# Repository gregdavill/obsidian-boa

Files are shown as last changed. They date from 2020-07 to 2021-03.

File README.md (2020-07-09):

# Obsidian Boa #

     ~ Current Status: Prototype boards ordered from OSHPark ~
     
     Note: This design was performed in KiCad nightly , you will need a Nightly build to open and edit these source files.

## Bare PCBs:
Order some PCBs
     [OSHPark](https://oshpark.com/shared_projects/r7u7eQDq)

## What is it?
A simple compact ESP32-S2 development board

Form-factor based off [bitsy-v1.0a](https://github.com/icebreaker-fpga/icebreaker/tree/master/hardware/bitsy-v1.0a)

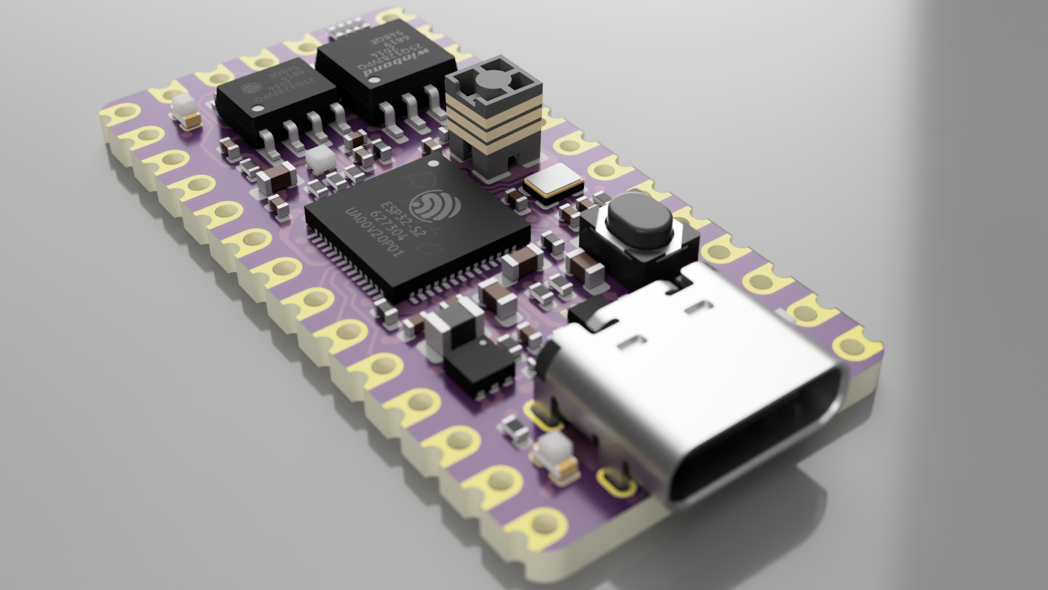
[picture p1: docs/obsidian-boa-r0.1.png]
Render


## What is it?
ESP32-S2 + PSRAM + FLASH

## Licence
 * Hardware in this repository is licenced under Creative Commons BY-SA

 ## OSHW Certification
 TBD (Will apply when prototypes tested)

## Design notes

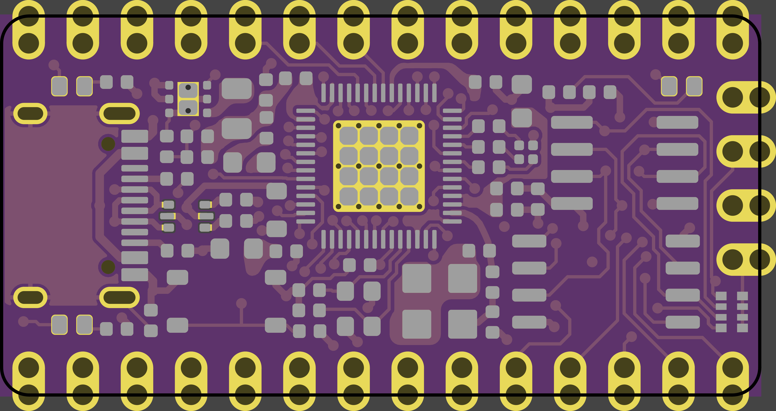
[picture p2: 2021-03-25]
hw/obsidian-boa-r0.1/Production/obsidian-boa-r0.1-Front.png

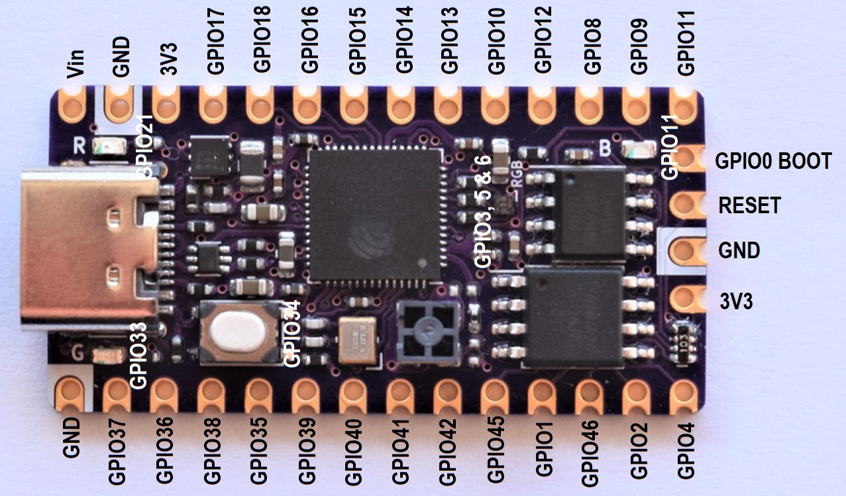
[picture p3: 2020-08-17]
hw/obsidian-boa-r0.1/obsidian-boa-pins-r0.1.jpg

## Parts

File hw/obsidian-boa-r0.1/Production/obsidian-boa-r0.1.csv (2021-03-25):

Source: | /home/greg/Projects/obsidian-boa/hw/obsidian-boa-r0.1/obsidian-boa-r0.1.kicad_sch
Date: | Thu 25 Mar 2021 13:59:01
Tool: | Eeschema 5.99.0-unknown-a9f86c6f3d~118~ubuntu20.10.1
Generator: | /usr/share/kicad-nightly/plugins/bom_csv_grouped_by_value.py
Component Count: | 87
Individual Components:
Item | Qty | Reference(s) | Value | LibPart | Footprint | Datasheet | Mfg | PN | Source
 |  | AE1 | Antenna | Device:Antenna_Shield | obsidian-boa:0479480001 | ~ | Molex | 0479480001
 |  | C1 | 2.2uF | icebreaker-bitsy-rescue:pkl_C_Small-pkl_device | Capacitor_SMD:C_0402_1005Metric |  | Yageo | CC0402MRX5R5BB225
 |  | C2 | 2.2uF | icebreaker-bitsy-rescue:pkl_C_Small-pkl_device | Capacitor_SMD:C_0402_1005Metric |  | Yageo | CC0402MRX5R5BB225
 |  | C3 | 18pF | icebreaker-bitsy-rescue:pkl_C_Small-pkl_device | Capacitor_SMD:C_0402_1005Metric |  | Yageo | CC0402GRNPO9BN180
 |  | C4 | 18pF | icebreaker-bitsy-rescue:pkl_C_Small-pkl_device | Capacitor_SMD:C_0402_1005Metric |  | Yageo | CC0402GRNPO9BN180
 |  | C5 | 10u | Device:C | Capacitor_SMD:C_0603_1608Metric | ~ | Yageo | CC0603KRX5R5BB106
 |  | C6 | 22pF | Device:C | Capacitor_SMD:C_0402_1005Metric | ~ | Yageo | CC0402KRNPO9BN220
 |  | C7 | 2.2uF | Device:C | Capacitor_SMD:C_0402_1005Metric | ~ | Yageo | CC0402MRX5R5BB225
 |  | C8 | 10u | icebreaker-bitsy-rescue:pkl_C-pkl_device | Capacitor_SMD:C_0603_1608Metric |  | Yageo | CC0603KRX5R5BB106
 |  | C9 | 100n | icebreaker-bitsy-rescue:pkl_C_Small-pkl_device | Capacitor_SMD:C_0402_1005Metric |  | Yageo | CC0402ZRY5V7BB104
 |  | C10 | TBD | icebreaker-bitsy-rescue:pkl_C_Small-pkl_device | Capacitor_SMD:C_0402_1005Metric |  |  | DNP | ANY
 |  | C11 | TBD | icebreaker-bitsy-rescue:pkl_C_Small-pkl_device | Capacitor_SMD:C_0402_1005Metric |  |  | DNP | ANY
 |  | C12 | 100n | icebreaker-bitsy-rescue:pkl_C_Small-pkl_device | Capacitor_SMD:C_0402_1005Metric |  | Yageo | CC0402ZRY5V7BB104
 |  | C13 | 100n | icebreaker-bitsy-rescue:pkl_C_Small-pkl_device | Capacitor_SMD:C_0402_1005Metric |  | Yageo | CC0402ZRY5V7BB104
 |  | C14 | 10u | icebreaker-bitsy-rescue:pkl_C-pkl_device | Capacitor_SMD:C_0603_1608Metric |  | Yageo | CC0603KRX5R5BB106
 |  | C15 | 100n | icebreaker-bitsy-rescue:pkl_C_Small-pkl_device | Capacitor_SMD:C_0402_1005Metric |  | Yageo | CC0402ZRY5V7BB104
 |  | C19 | 10u | icebreaker-bitsy-rescue:pkl_C-pkl_device | Capacitor_SMD:C_0603_1608Metric |  | Yageo | CC0603KRX5R5BB106
 |  | D1 | RED | Device:LED_ALT | obsidian-boa:LED_0603_1608Metric_Compact | ~ | Lite-On Inc. | LTST-C191KRKT
 |  | D2 | GRN | Device:LED_ALT | obsidian-boa:LED_0603_1608Metric_Compact | ~ | Lite-On Inc. | LTST-C191KGKT
 |  | D3 | BLU | Device:LED_ALT | obsidian-boa:LED_0603_1608Metric_Compact | ~ | Lite-On Inc. | LTST-C191TBKT
 |  | D4 | MHPA1010RGBDT | Device:LED_ARBG | LED_SMD:LED_Lumex_SML-LX0303SIUPGUSB | ~ | MEIHUA | MHPA1010RGBDT
 |  | FB1 | 240R | Device:Ferrite_Bead_Small | Inductor_SMD:L_0402_1005Metric | ~ | Murata Electronics | BLM15BC241SN1D
 |  | FB2 | 240R | Device:Ferrite_Bead_Small | Inductor_SMD:L_0402_1005Metric | ~ | Murata Electronics | BLM15BC241SN1D
 |  | FB3 | 240R | Device:Ferrite_Bead_Small | Inductor_SMD:L_0402_1005Metric | ~ | Murata Electronics | BLM15BC241SN1D
 |  | J1 | USB_C | Connector:USB_C_Receptacle_USB2.0 | pkl_connectors:USB_C_Receptacle_HRO_TYPE-C-31-M-12 | https://www.usb.org/sites/default/files/documents/usb_type-c.zip | GCT | USB4105-GF-A
 |  | J2 | PROG | Connector_Generic:Conn_02x05_Odd_Even | pkl_pin_headers:PinHeader_2x05_P2.54mm_Vertical_SMD | ~
 |  | JP1 | Jumper | icebreaker-bitsy-rescue:pkl_jumper_nc-pkl_misc | Jumper:SolderJumper-2_P1.3mm_Bridged2Bar_RoundedPad1.0x1.5mm |  |  |  | ANY
 |  | L1 | 2.2uH | Device:L_Small | Inductor_SMD:L_0805_2012Metric | ~ | TAI-TECH | CPI201210UF-2R2M-0A8
 |  | L2 | TBD | Device:L_Small | Inductor_SMD:L_0402_1005Metric | ~ | Yageo | RC0402FR-070RL
 |  | P0 | 0 | Connector_Generic:Conn_01x01 | pkl_pin_headers:Pin_Header_Straight_Round_1x01_Castellated | ~ |  |  | ANY
 |  | P1 | 1 | Connector_Generic:Conn_01x01 | pkl_pin_headers:Pin_Header_Straight_Round_1x01_Castellated | ~ |  |  | ANY
 |  | P2 | 2 | Connector_Generic:Conn_01x01 | pkl_pin_headers:Pin_Header_Straight_Round_1x01_Castellated | ~ |  |  | ANY
 |  | P3 | 3 | Connector_Generic:Conn_01x01 | pkl_pin_headers:Pin_Header_Straight_Round_1x01_Castellated | ~ |  |  | ANY
 |  | P4 | 4 | Connector_Generic:Conn_01x01 | pkl_pin_headers:Pin_Header_Straight_Round_1x01_Castellated | ~ |  |  | ANY
 |  | P5 | 5 | Connector_Generic:Conn_01x01 | pkl_pin_headers:Pin_Header_Straight_Round_1x01_Castellated | ~ |  |  | ANY
 |  | P6 | 6 | Connector_Generic:Conn_01x01 | pkl_pin_headers:Pin_Header_Straight_Round_1x01_Castellated | ~ |  |  | ANY
 |  | P7 | 7 | Connector_Generic:Conn_01x01 | pkl_pin_headers:Pin_Header_Straight_Round_1x01_Castellated | ~ |  |  | ANY
 |  | P8 | 8 | Connector_Generic:Conn_01x01 | pkl_pin_headers:Pin_Header_Straight_Round_1x01_Castellated | ~ |  |  | ANY
 |  | P9 | 9 | Connector_Generic:Conn_01x01 | pkl_pin_headers:Pin_Header_Straight_Round_1x01_Castellated | ~ |  |  | ANY
 |  | P10 | 10 | Connector_Generic:Conn_01x01 | pkl_pin_headers:Pin_Header_Straight_Round_1x01_Castellated | ~ |  |  | ANY
 |  | P11 | 11 | Connector_Generic:Conn_01x01 | pkl_pin_headers:Pin_Header_Straight_Round_1x01_Castellated | ~ |  |  | ANY
 |  | P12 | 12 | Connector_Generic:Conn_01x01 | pkl_pin_headers:Pin_Header_Straight_Round_1x01_Castellated | ~ |  |  | ANY
 |  | P13 | 13 | Connector_Generic:Conn_01x01 | pkl_pin_headers:Pin_Header_Straight_Round_1x01_Castellated | ~ |  |  | ANY
 |  | P14 | 14 | Connector_Generic:Conn_01x01 | pkl_pin_headers:Pin_Header_Straight_Round_1x01_Castellated | ~ |  |  | ANY
 |  | P15 | 15 | Connector_Generic:Conn_01x01 | pkl_pin_headers:Pin_Header_Straight_Round_1x01_Castellated | ~ |  |  | ANY
 |  | P16 | 16 | Connector_Generic:Conn_01x01 | pkl_pin_headers:Pin_Header_Straight_Round_1x01_Castellated | ~ |  |  | ANY
 |  | P17 | 17 | Connector_Generic:Conn_01x01 | pkl_pin_headers:Pin_Header_Straight_Round_1x01_Castellated | ~ |  |  | ANY
 |  | P18 | 18 | Connector_Generic:Conn_01x01 | pkl_pin_headers:Pin_Header_Straight_Round_1x01_Castellated | ~ |  |  | ANY
 |  | P19 | 19 | Connector_Generic:Conn_01x01 | pkl_pin_headers:Pin_Header_Straight_Round_1x01_Castellated | ~ |  |  | ANY
 |  | P20 | 20 | Connector_Generic:Conn_01x01 | pkl_pin_headers:Pin_Header_Straight_Round_1x01_Castellated | ~ |  |  | ANY
 |  | P21 | 21 | Connector_Generic:Conn_01x01 | pkl_pin_headers:Pin_Header_Straight_Round_1x01_Castellated | ~ |  |  | ANY
 |  | P22 | 22 | Connector_Generic:Conn_01x01 | pkl_pin_headers:Pin_Header_Straight_Round_1x01_Castellated | ~ |  |  | ANY
 |  | P23 | 23 | Connector_Generic:Conn_01x01 | pkl_pin_headers:Pin_Header_Straight_Round_1x01_Castellated | ~ |  |  | ANY
 |  | P24 | GND | Connector_Generic:Conn_01x01 | pkl_pin_headers:Pin_Header_Straight_Round_1x01_Castellated | ~ |  |  | ANY
 |  | P25 | GND | Connector_Generic:Conn_01x01 | pkl_pin_headers:Pin_Header_Straight_Round_1x01_Castellated | ~ |  |  | ANY
 |  | P26 | GND | Connector_Generic:Conn_01x01 | pkl_pin_headers:Pin_Header_Straight_Round_1x01_Castellated | ~ |  |  | ANY
 |  | P27 | 3V3 | Connector_Generic:Conn_01x01 | pkl_pin_headers:Pin_Header_Straight_Round_1x01_Castellated | ~ |  |  | ANY
 |  | P28 | 3V3 | Connector_Generic:Conn_01x01 | pkl_pin_headers:Pin_Header_Straight_Round_1x01_Castellated | ~ |  |  | ANY
 |  | P29 | VIN | Connector_Generic:Conn_01x01 | pkl_pin_headers:Pin_Header_Straight_Round_1x01_Castellated | ~ |  |  | ANY
 |  | P30 | CDONE | Connector_Generic:Conn_01x01 | pkl_pin_headers:Pin_Header_Straight_Round_1x01_Castellated | ~ |  |  | ANY
 |  | P31 | CRESET | Connector_Generic:Conn_01x01 | pkl_pin_headers:Pin_Header_Straight_Round_1x01_Castellated | ~ |  |  | ANY
 |  | P32 | UP | icebreaker-bitsy-rescue:PAD_SMD-pkl_misc | pkl_pads:PAD_SMD_1x2.65_ROUNDED |  |  |  | ANY
 |  | P33 | UP | icebreaker-bitsy-rescue:PAD_SMD-pkl_misc | pkl_pads:PAD_SMD_1x2.65_ROUNDED |  |  |  | ANY
 |  | P34 | UP | icebreaker-bitsy-rescue:PAD_SMD-pkl_misc | pkl_pads:PAD_SMD_1x2.65_ROUNDED |  |  |  | ANY
 |  | P35 | UP | icebreaker-bitsy-rescue:PAD_SMD-pkl_misc | pkl_pads:PAD_SMD_1x2.65_ROUNDED |  |  |  | ANY
 |  | R1 | 1M | icebreaker-bitsy-rescue:pkl_R_Small-pkl_device | Resistor_SMD:R_0402_1005Metric |  | Yageo | RC0402FR-071ML
 |  | R2 | 5k1 | icebreaker-bitsy-rescue:pkl_R_Small-pkl_device | Resistor_SMD:R_0402_1005Metric |  | Yageo | RC0402FR-075K1L
 |  | R3 | 5k1 | icebreaker-bitsy-rescue:pkl_R_Small-pkl_device | Resistor_SMD:R_0402_1005Metric |  | Yageo | RC0402FR-075K1L
 |  | R4 | 22E | icebreaker-bitsy-rescue:pkl_R_Small-pkl_device | Resistor_SMD:R_0402_1005Metric |  | Yageo | RC0402FR-0722RL
 |  | R5 | 22E | icebreaker-bitsy-rescue:pkl_R_Small-pkl_device | Resistor_SMD:R_0402_1005Metric |  | Yageo | RC0402FR-0722RL
 |  | R6 | 2k2 | icebreaker-bitsy-rescue:pkl_R_Small-pkl_device | Resistor_SMD:R_0402_1005Metric |  | Yageo | RC0402FR-072K2L
 |  | R7 | 453k | Device:R | Resistor_SMD:R_0402_1005Metric | ~ | Yageo | RC0402FR-07453KL
 |  | R8 | 100k | Device:R | Resistor_SMD:R_0402_1005Metric | ~ | Yageo | RC0402FR-07100KL
 |  | R9 | 2k2 | icebreaker-bitsy-rescue:pkl_R_Small-pkl_device | Resistor_SMD:R_0402_1005Metric |  | Yageo | RC0402FR-072K2L
 |  | R10 | 10k | icebreaker-bitsy-rescue:pkl_R_Small-pkl_device | Resistor_SMD:R_0402_1005Metric |  | Yageo | RC0402FR-0710KL
 |  | R11 | 330E | icebreaker-bitsy-rescue:pkl_R_Small-pkl_device | Resistor_SMD:R_0402_1005Metric |  | Yageo | RC0402FR-07330RL
 |  | R12 | 330E | icebreaker-bitsy-rescue:pkl_R_Small-pkl_device | Resistor_SMD:R_0402_1005Metric |  | Yageo | RC0402FR-07330RL
 |  | R13 | 2k2 | icebreaker-bitsy-rescue:pkl_R_Small-pkl_device | Resistor_SMD:R_0402_1005Metric |  | Yageo | RC0402FR-072K2L
 |  | R14 | 2k2 | icebreaker-bitsy-rescue:pkl_R_Small-pkl_device | Resistor_SMD:R_0402_1005Metric |  | Yageo | RC0402FR-072K2L
 |  | RN1 | 10k | Device:R_Pack04_Split | Resistor_SMD:R_Array_Convex_4x0402 | ~ | Yageo | YC124-FR-0710KL
 |  | SW1 | TACT | icebreaker-bitsy-rescue:TACT-pkl_misc | pkl_buttons_switches:SW_SPST_3x4x2.5 |  | C&K | PTS810
 |  | U1 | USBLC6-2 | icebreaker-bitsy-rescue:USBLC6-2-pkl_misc | pkl_housings_sot:SOT-666 |  | STMicroelectronics | USBLC6-2P6
 |  | U2 | LY68L6400SLIT | Memory_Flash:W25Q32JVSS | Package_SO:SOIC-8_3.9x4.9mm_P1.27mm | http://www.winbond.com/resource-files/w25q32jv%20revg%2003272018%20plus.pdf | Lyontek Inc. | LY68L6400SLIT
 |  | U3 | ESP32-S2 | obsidian-boa:ESP32-S2 | Package_DFN_QFN:QFN-56-1EP_7x7mm_P0.4mm_EP5.6x5.6mm |  | Espressif Systems | ESP32-S2
 |  | U4 | W25Q128JV | Memory_Flash:W25Q32JVSS | Package_SO:SOIC-8_5.23x5.23mm_P1.27mm | http://www.winbond.com/resource-files/w25q32jv%20revg%2003272018%20plus.pdf | Winbond Electronics | W25Q128JVSIQ TR
 |  | U5 | TPS62290 | gkl_pmic:TPS62290 | Package_SON:WSON-6-1EP_2x2mm_P0.65mm_EP1x1.6mm_ThermalVias |  | Texas Instruments | TPS62290DRVR
 |  | Y1 | 40MHz | Device:Crystal_GND24_Small | Crystal:Crystal_SMD_Abracon_ABM10-4Pin_2.5x2.0mm | ~ | ECS Inc. | ECS-400-10-36B-CKY-TR
Collated Components:
Item | Qty | Reference(s) | Value | LibPart | Footprint | Datasheet | Mfg | PN | Source
1 | 1 | AE1 | Antenna | Device:Antenna_Shield | obsidian-boa:0479480001 | ~ | Molex | 0479480001
2 | 2 | C1, C2 | 2.2uF | icebreaker-bitsy-rescue:pkl_C_Small-pkl_device | Capacitor_SMD:C_0402_1005Metric |  | Yageo | CC0402MRX5R5BB225
3 | 2 | C3, C4 | 18pF | icebreaker-bitsy-rescue:pkl_C_Small-pkl_device | Capacitor_SMD:C_0402_1005Metric |  | Yageo | CC0402GRNPO9BN180
4 | 1 | C5 | 10u | Device:C | Capacitor_SMD:C_0603_1608Metric | ~ | Yageo | CC0603KRX5R5BB106
5 | 1 | C6 | 22pF | Device:C | Capacitor_SMD:C_0402_1005Metric | ~ | Yageo | CC0402KRNPO9BN220
6 | 1 | C7 | 2.2uF | Device:C | Capacitor_SMD:C_0402_1005Metric | ~ | Yageo | CC0402MRX5R5BB225
7 | 3 | C8, C14, C19 | 10u | icebreaker-bitsy-rescue:pkl_C-pkl_device | Capacitor_SMD:C_0603_1608Metric |  | Yageo | CC0603KRX5R5BB106
8 | 4 | C9, C12, C13, C15 | 100n | icebreaker-bitsy-rescue:pkl_C_Small-pkl_device | Capacitor_SMD:C_0402_1005Metric |  | Yageo | CC0402ZRY5V7BB104
9 | 2 | C10, C11 | TBD | icebreaker-bitsy-rescue:pkl_C_Small-pkl_device | Capacitor_SMD:C_0402_1005Metric |  |  | DNP | ANY
10 | 1 | D1 | RED | Device:LED_ALT | obsidian-boa:LED_0603_1608Metric_Compact | ~ | Lite-On Inc. | LTST-C191KRKT
11 | 1 | D2 | GRN | Device:LED_ALT | obsidian-boa:LED_0603_1608Metric_Compact | ~ | Lite-On Inc. | LTST-C191KGKT
12 | 1 | D3 | BLU | Device:LED_ALT | obsidian-boa:LED_0603_1608Metric_Compact | ~ | Lite-On Inc. | LTST-C191TBKT
13 | 1 | D4 | MHPA1010RGBDT | Device:LED_ARBG | LED_SMD:LED_Lumex_SML-LX0303SIUPGUSB | ~ | MEIHUA | MHPA1010RGBDT
14 | 3 | FB1, FB2, FB3 | 240R | Device:Ferrite_Bead_Small | Inductor_SMD:L_0402_1005Metric | ~ | Murata Electronics | BLM15BC241SN1D
15 | 1 | J1 | USB_C | Connector:USB_C_Receptacle_USB2.0 | pkl_connectors:USB_C_Receptacle_HRO_TYPE-C-31-M-12 | https://www.usb.org/sites/default/files/documents/usb_type-c.zip | GCT | USB4105-GF-A
16 | 1 | J2 | PROG | Connector_Generic:Conn_02x05_Odd_Even | pkl_pin_headers:PinHeader_2x05_P2.54mm_Vertical_SMD | ~
17 | 1 | JP1 | Jumper | icebreaker-bitsy-rescue:pkl_jumper_nc-pkl_misc | Jumper:SolderJumper-2_P1.3mm_Bridged2Bar_RoundedPad1.0x1.5mm |  |  |  | ANY
18 | 1 | L1 | 2.2uH | Device:L_Small | Inductor_SMD:L_0805_2012Metric | ~ | TAI-TECH | CPI201210UF-2R2M-0A8
19 | 1 | L2 | TBD | Device:L_Small | Inductor_SMD:L_0402_1005Metric | ~ | Yageo | RC0402FR-070RL
20 | 1 | P0 | 0 | Connector_Generic:Conn_01x01 | pkl_pin_headers:Pin_Header_Straight_Round_1x01_Castellated | ~ |  |  | ANY
21 | 1 | P1 | 1 | Connector_Generic:Conn_01x01 | pkl_pin_headers:Pin_Header_Straight_Round_1x01_Castellated | ~ |  |  | ANY
22 | 1 | P2 | 2 | Connector_Generic:Conn_01x01 | pkl_pin_headers:Pin_Header_Straight_Round_1x01_Castellated | ~ |  |  | ANY
23 | 1 | P3 | 3 | Connector_Generic:Conn_01x01 | pkl_pin_headers:Pin_Header_Straight_Round_1x01_Castellated | ~ |  |  | ANY
24 | 1 | P4 | 4 | Connector_Generic:Conn_01x01 | pkl_pin_headers:Pin_Header_Straight_Round_1x01_Castellated | ~ |  |  | ANY
25 | 1 | P5 | 5 | Connector_Generic:Conn_01x01 | pkl_pin_headers:Pin_Header_Straight_Round_1x01_Castellated | ~ |  |  | ANY
26 | 1 | P6 | 6 | Connector_Generic:Conn_01x01 | pkl_pin_headers:Pin_Header_Straight_Round_1x01_Castellated | ~ |  |  | ANY
27 | 1 | P7 | 7 | Connector_Generic:Conn_01x01 | pkl_pin_headers:Pin_Header_Straight_Round_1x01_Castellated | ~ |  |  | ANY
28 | 1 | P8 | 8 | Connector_Generic:Conn_01x01 | pkl_pin_headers:Pin_Header_Straight_Round_1x01_Castellated | ~ |  |  | ANY
29 | 1 | P9 | 9 | Connector_Generic:Conn_01x01 | pkl_pin_headers:Pin_Header_Straight_Round_1x01_Castellated | ~ |  |  | ANY
30 | 1 | P10 | 10 | Connector_Generic:Conn_01x01 | pkl_pin_headers:Pin_Header_Straight_Round_1x01_Castellated | ~ |  |  | ANY
31 | 1 | P11 | 11 | Connector_Generic:Conn_01x01 | pkl_pin_headers:Pin_Header_Straight_Round_1x01_Castellated | ~ |  |  | ANY
32 | 1 | P12 | 12 | Connector_Generic:Conn_01x01 | pkl_pin_headers:Pin_Header_Straight_Round_1x01_Castellated | ~ |  |  | ANY
33 | 1 | P13 | 13 | Connector_Generic:Conn_01x01 | pkl_pin_headers:Pin_Header_Straight_Round_1x01_Castellated | ~ |  |  | ANY
34 | 1 | P14 | 14 | Connector_Generic:Conn_01x01 | pkl_pin_headers:Pin_Header_Straight_Round_1x01_Castellated | ~ |  |  | ANY
35 | 1 | P15 | 15 | Connector_Generic:Conn_01x01 | pkl_pin_headers:Pin_Header_Straight_Round_1x01_Castellated | ~ |  |  | ANY
36 | 1 | P16 | 16 | Connector_Generic:Conn_01x01 | pkl_pin_headers:Pin_Header_Straight_Round_1x01_Castellated | ~ |  |  | ANY
37 | 1 | P17 | 17 | Connector_Generic:Conn_01x01 | pkl_pin_headers:Pin_Header_Straight_Round_1x01_Castellated | ~ |  |  | ANY
38 | 1 | P18 | 18 | Connector_Generic:Conn_01x01 | pkl_pin_headers:Pin_Header_Straight_Round_1x01_Castellated | ~ |  |  | ANY
39 | 1 | P19 | 19 | Connector_Generic:Conn_01x01 | pkl_pin_headers:Pin_Header_Straight_Round_1x01_Castellated | ~ |  |  | ANY
40 | 1 | P20 | 20 | Connector_Generic:Conn_01x01 | pkl_pin_headers:Pin_Header_Straight_Round_1x01_Castellated | ~ |  |  | ANY
41 | 1 | P21 | 21 | Connector_Generic:Conn_01x01 | pkl_pin_headers:Pin_Header_Straight_Round_1x01_Castellated | ~ |  |  | ANY
42 | 1 | P22 | 22 | Connector_Generic:Conn_01x01 | pkl_pin_headers:Pin_Header_Straight_Round_1x01_Castellated | ~ |  |  | ANY
43 | 1 | P23 | 23 | Connector_Generic:Conn_01x01 | pkl_pin_headers:Pin_Header_Straight_Round_1x01_Castellated | ~ |  |  | ANY
44 | 3 | P24, P25, P26 | GND | Connector_Generic:Conn_01x01 | pkl_pin_headers:Pin_Header_Straight_Round_1x01_Castellated | ~ |  |  | ANY
45 | 2 | P27, P28 | 3V3 | Connector_Generic:Conn_01x01 | pkl_pin_headers:Pin_Header_Straight_Round_1x01_Castellated | ~ |  |  | ANY
46 | 1 | P29 | VIN | Connector_Generic:Conn_01x01 | pkl_pin_headers:Pin_Header_Straight_Round_1x01_Castellated | ~ |  |  | ANY
47 | 1 | P30 | CDONE | Connector_Generic:Conn_01x01 | pkl_pin_headers:Pin_Header_Straight_Round_1x01_Castellated | ~ |  |  | ANY
48 | 1 | P31 | CRESET | Connector_Generic:Conn_01x01 | pkl_pin_headers:Pin_Header_Straight_Round_1x01_Castellated | ~ |  |  | ANY
49 | 4 | P32, P33, P34, P35 | UP | icebreaker-bitsy-rescue:PAD_SMD-pkl_misc | pkl_pads:PAD_SMD_1x2.65_ROUNDED |  |  |  | ANY
50 | 1 | R1 | 1M | icebreaker-bitsy-rescue:pkl_R_Small-pkl_device | Resistor_SMD:R_0402_1005Metric |  | Yageo | RC0402FR-071ML
51 | 2 | R2, R3 | 5k1 | icebreaker-bitsy-rescue:pkl_R_Small-pkl_device | Resistor_SMD:R_0402_1005Metric |  | Yageo | RC0402FR-075K1L
52 | 2 | R4, R5 | 22E | icebreaker-bitsy-rescue:pkl_R_Small-pkl_device | Resistor_SMD:R_0402_1005Metric |  | Yageo | RC0402FR-0722RL
53 | 4 | R6, R9, R13, R14 | 2k2 | icebreaker-bitsy-rescue:pkl_R_Small-pkl_device | Resistor_SMD:R_0402_1005Metric |  | Yageo | RC0402FR-072K2L
54 | 1 | R7 | 453k | Device:R | Resistor_SMD:R_0402_1005Metric | ~ | Yageo | RC0402FR-07453KL
55 | 1 | R8 | 100k | Device:R | Resistor_SMD:R_0402_1005Metric | ~ | Yageo | RC0402FR-07100KL
56 | 1 | R10 | 10k | icebreaker-bitsy-rescue:pkl_R_Small-pkl_device | Resistor_SMD:R_0402_1005Metric |  | Yageo | RC0402FR-0710KL
57 | 2 | R11, R12 | 330E | icebreaker-bitsy-rescue:pkl_R_Small-pkl_device | Resistor_SMD:R_0402_1005Metric |  | Yageo | RC0402FR-07330RL
58 | 1 | RN1 | 10k | Device:R_Pack04_Split | Resistor_SMD:R_Array_Convex_4x0402 | ~ | Yageo | YC124-FR-0710KL
59 | 1 | SW1 | TACT | icebreaker-bitsy-rescue:TACT-pkl_misc | pkl_buttons_switches:SW_SPST_3x4x2.5 |  | C&K | PTS810
60 | 1 | U1 | USBLC6-2 | icebreaker-bitsy-rescue:USBLC6-2-pkl_misc | pkl_housings_sot:SOT-666 |  | STMicroelectronics | USBLC6-2P6
61 | 1 | U2 | LY68L6400SLIT | Memory_Flash:W25Q32JVSS | Package_SO:SOIC-8_3.9x4.9mm_P1.27mm | http://www.winbond.com/resource-files/w25q32jv%20revg%2003272018%20plus.pdf | Lyontek Inc. | LY68L6400SLIT
62 | 1 | U3 | ESP32-S2 | obsidian-boa:ESP32-S2 | Package_DFN_QFN:QFN-56-1EP_7x7mm_P0.4mm_EP5.6x5.6mm |  | Espressif Systems | ESP32-S2
63 | 1 | U4 | W25Q128JV | Memory_Flash:W25Q32JVSS | Package_SO:SOIC-8_5.23x5.23mm_P1.27mm | http://www.winbond.com/resource-files/w25q32jv%20revg%2003272018%20plus.pdf | Winbond Electronics | W25Q128JVSIQ TR
64 | 1 | U5 | TPS62290 | gkl_pmic:TPS62290 | Package_SON:WSON-6-1EP_2x2mm_P0.65mm_EP1x1.6mm_ThermalVias |  | Texas Instruments | TPS62290DRVR
65 | 1 | Y1 | 40MHz | Device:Crystal_GND24_Small | Crystal:Crystal_SMD_Abracon_ABM10-4Pin_2.5x2.0mm | ~ | ECS Inc. | ECS-400-10-36B-CKY-TR

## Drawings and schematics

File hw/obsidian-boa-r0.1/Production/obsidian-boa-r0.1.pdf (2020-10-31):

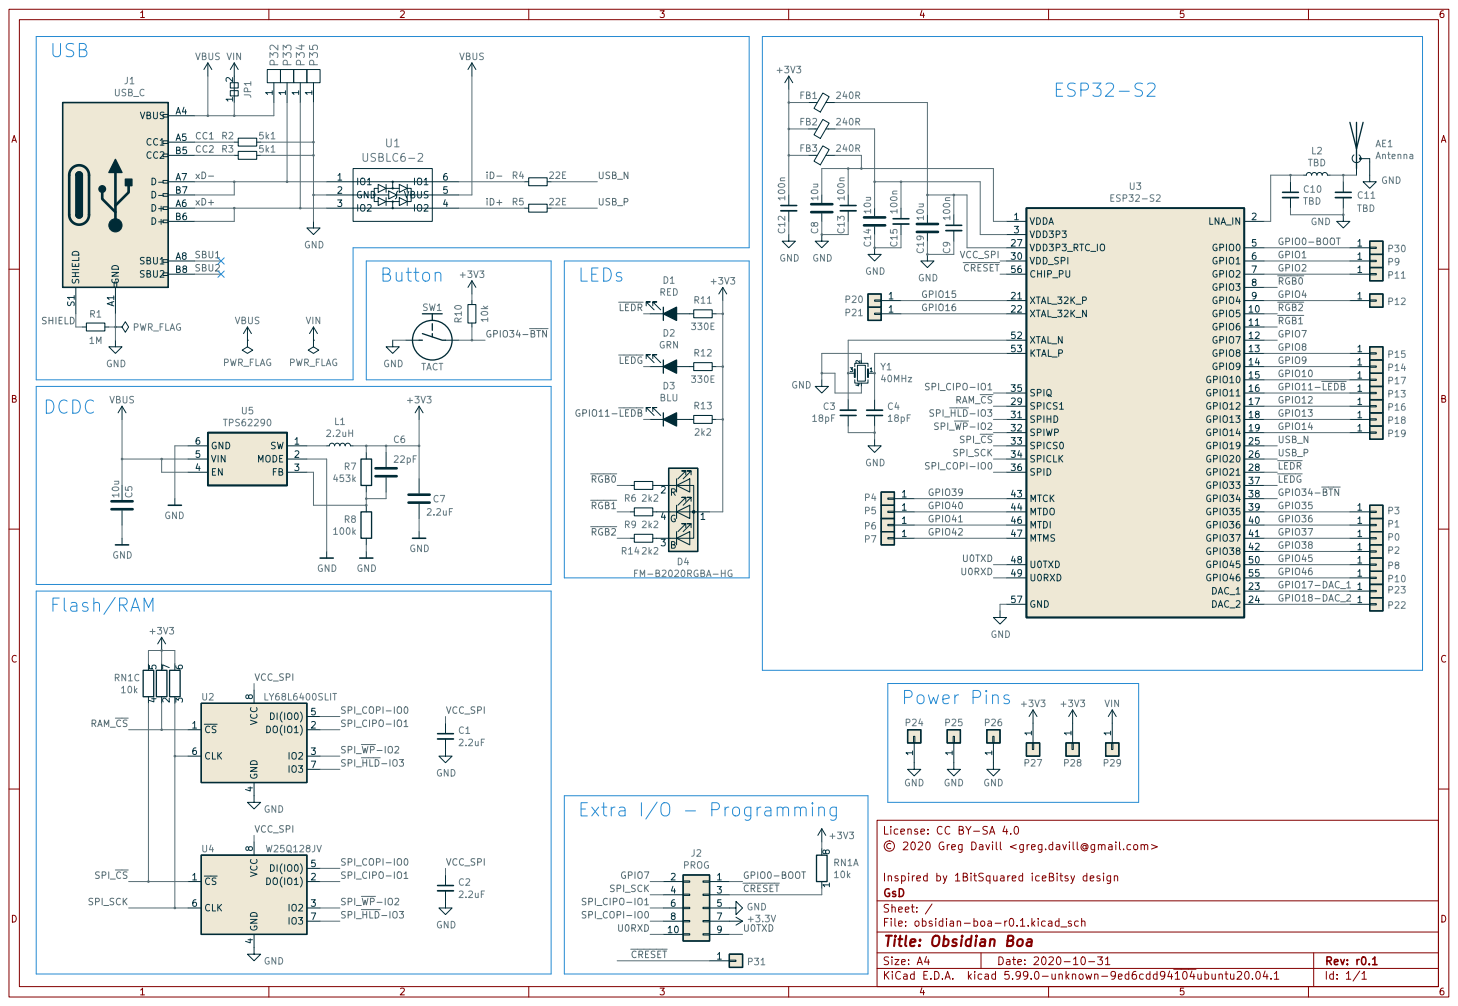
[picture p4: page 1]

License: CC BY-SA 4.0GND

Inspired by 1BitSquared iceBitsy design
File: obsidian-boa-r0.1.kicad_sch Sheet: / GsD

Id: 1/1 Title: Obsidian Boa

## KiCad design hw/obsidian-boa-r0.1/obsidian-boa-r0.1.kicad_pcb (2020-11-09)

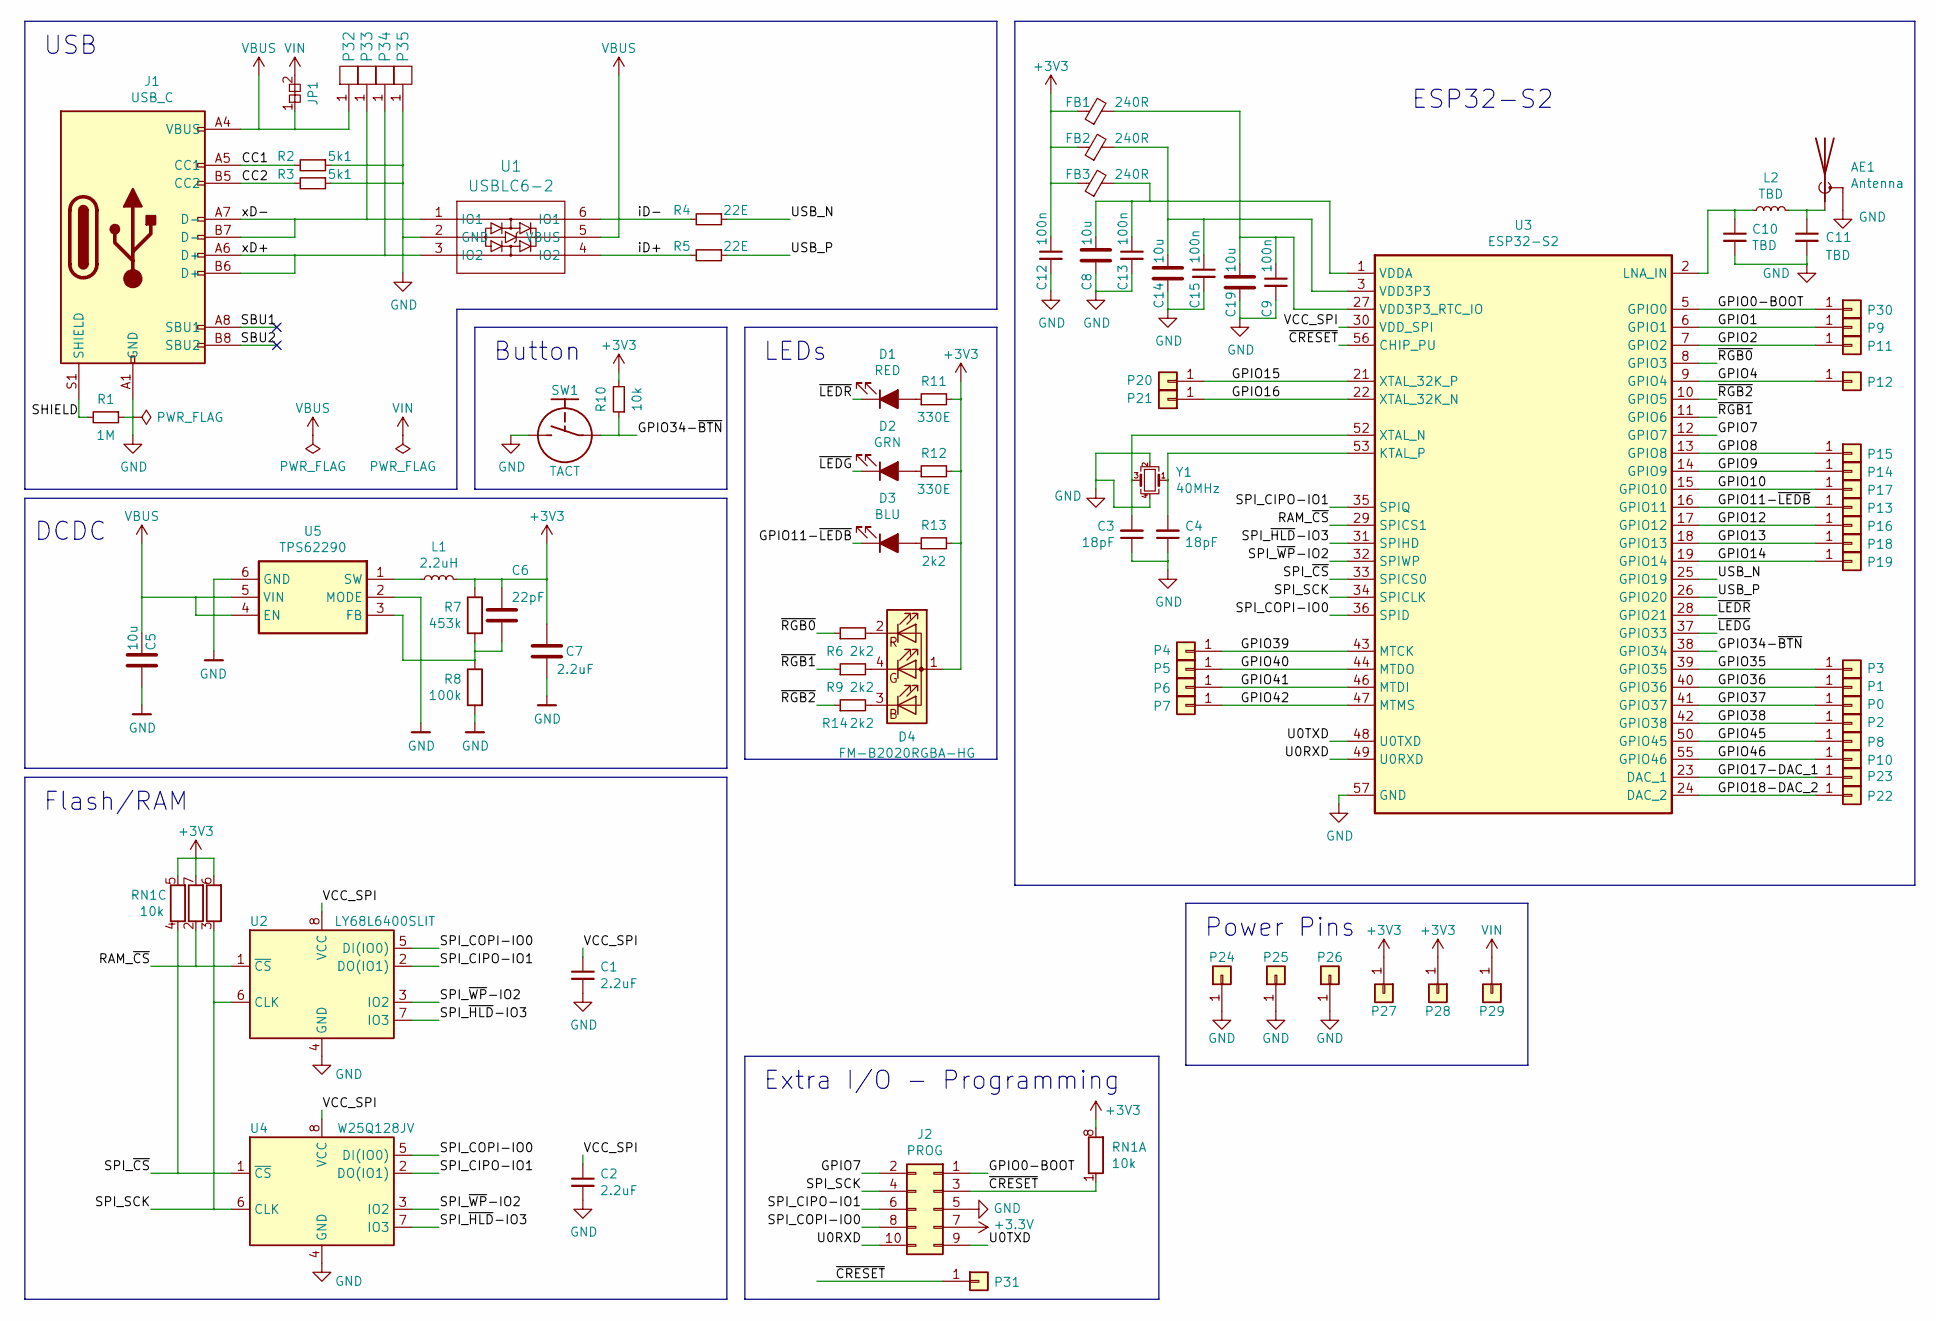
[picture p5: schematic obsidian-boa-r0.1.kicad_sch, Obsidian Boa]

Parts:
AE1: Antenna; 0479480001
C1, C2, C7: 2.2uF; C_0402_1005Metric
C3, C4: 18pF; C_0402_1005Metric
C5, C8, C14, C19: 10u; C_0603_1608Metric
C6: 22pF; C_0402_1005Metric
C9, C12, C13, C15: 100n; C_0402_1005Metric
C10, C11: TBD; C_0402_1005Metric
D1: RED; LED_0603_1608Metric_Compact
D2: GRN; LED_0603_1608Metric_Compact
D3: BLU; LED_0603_1608Metric_Compact
D4: FM-B2020RGBA-HG; LED_Lumex_SML-LX0303SIUPGUSB
FB1, FB2, FB3: 240R; L_0402_1005Metric
J1: USB_C; USB_C_Receptacle_HRO_TYPE-C-31-M-12
J2: PROG; PinHeader_2x05_P2.54mm_Vertical_SMD
JP1: Jumper; SolderJumper-2_P1.3mm_Bridged2Bar_RoundedPad1.0x1.5mm
L1: 2.2uH; L_0805_2012Metric
L2: TBD; L_0402_1005Metric
P0: 0; Pin_Header_Straight_Round_1x01_Castellated
P1: 1; Pin_Header_Straight_Round_1x01_Castellated
P2: 2; Pin_Header_Straight_Round_1x01_Castellated
P3: 3; Pin_Header_Straight_Round_1x01_Castellated
P4: 4; Pin_Header_Straight_Round_1x01_Castellated
P5: 5; Pin_Header_Straight_Round_1x01_Castellated
P6: 6; Pin_Header_Straight_Round_1x01_Castellated
P7: 7; Pin_Header_Straight_Round_1x01_Castellated
P8: 8; Pin_Header_Straight_Round_1x01_Castellated
P9: 9; Pin_Header_Straight_Round_1x01_Castellated
P10: 10; Pin_Header_Straight_Round_1x01_Castellated
P11: 11; Pin_Header_Straight_Round_1x01_Castellated
P12: 12; Pin_Header_Straight_Round_1x01_Castellated
P13: 13; Pin_Header_Straight_Round_1x01_Castellated
P14: 14; Pin_Header_Straight_Round_1x01_Castellated
P15: 15; Pin_Header_Straight_Round_1x01_Castellated
P16: 16; Pin_Header_Straight_Round_1x01_Castellated
P17: 17; Pin_Header_Straight_Round_1x01_Castellated
P18: 18; Pin_Header_Straight_Round_1x01_Castellated
P19: 19; Pin_Header_Straight_Round_1x01_Castellated
P20: 20; Pin_Header_Straight_Round_1x01_Castellated
P21: 21; Pin_Header_Straight_Round_1x01_Castellated
P22: 22; Pin_Header_Straight_Round_1x01_Castellated
P23: 23; Pin_Header_Straight_Round_1x01_Castellated
P24, P25, P26: GND; Pin_Header_Straight_Round_1x01_Castellated
P27, P28: 3V3; Pin_Header_Straight_Round_1x01_Castellated
P29: VIN; Pin_Header_Straight_Round_1x01_Castellated
P30: CDONE; Pin_Header_Straight_Round_1x01_Castellated
P31: CRESET; Pin_Header_Straight_Round_1x01_Castellated
P32, P33, P34, P35: UP; PAD_SMD_1x2.65_ROUNDED
R1: 1M; R_0402_1005Metric
R2, R3: 5k1; R_0402_1005Metric
R4, R5: 22E; R_0402_1005Metric
R6, R9, R13, R14: 2k2; R_0402_1005Metric
R7: 453k; R_0402_1005Metric
R8: 100k; R_0402_1005Metric
R10: 10k; R_0402_1005Metric
R11, R12: 330E; R_0402_1005Metric
RN1: 10k; R_Array_Convex_4x0402
SW1: TACT; SW_SPST_3x4x2.5
U1: USBLC6-2; SOT-666
U2: LY68L6400SLIT; SOIC-8_3.9x4.9mm_P1.27mm
U3: ESP32-S2; QFN-56-1EP_7x7mm_P0.4mm_EP5.6x5.6mm
U4: W25Q128JV; SOIC-8_5.23x5.23mm_P1.27mm
U5: TPS62290; WSON-6-1EP_2x2mm_P0.65mm_EP1x1.6mm_ThermalVias
Y1: 40MHz; Crystal_SMD_Abracon_ABM10-4Pin_2.5x2.0mm

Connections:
/CC1: J1.A5 (CC1), R2.2
/CC2: J1.B5 (CC2), R3.2
/GPIO0-BOOT: J2.1, P30.1, U3.5 (GPIO0)
/GPIO1: P9.1, U3.6 (GPIO1)
/GPIO2: P11.1, U3.7 (GPIO2)
/GPIO4: P12.1, U3.9 (GPIO4)
/GPIO7: J2.2, U3.12 (GPIO7)
/GPIO8: P15.1, U3.13 (GPIO8)
/GPIO9: P14.1, U3.14 (GPIO9)
/GPIO10: P17.1, U3.15 (GPIO10)
/GPIO11-~LEDB: D3.1 (K), P13.1, U3.16 (GPIO11)
/GPIO12: P16.1, U3.17 (GPIO12)
/GPIO13: P18.1, U3.18 (GPIO13)
/GPIO14: P19.1, U3.19 (GPIO14)
/GPIO15: P20.1, U3.21 (XTAL_32K_P)
/GPIO16: P21.1, U3.22 (XTAL_32K_N)
/GPIO17-DAC_1: P23.1, U3.23 (DAC_1)
/GPIO18-DAC_2: P22.1, U3.24 (DAC_2)
/GPIO34-~BTN: R10.1, SW1.1, U3.38 (GPIO34)
/GPIO35: P3.1, U3.39 (GPIO35)
/GPIO36: P1.1, U3.40 (GPIO36)
/GPIO37: P0.1, U3.41 (GPIO37)
/GPIO38: P2.1, U3.42 (GPIO38)
/GPIO39: P4.1, U3.43 (MTCK)
/GPIO40: P5.1, U3.44 (MTDO)
/GPIO41: P6.1, U3.46 (MTDI)
/GPIO42: P7.1, U3.47 (MTMS)
/GPIO45: P8.1, U3.50 (GPIO45)
/GPIO46: P10.1, U3.55 (GPIO46)
/RAM_~CS: RN1.2 (R2.1), U2.1 (~CS), U3.29 (SPICS1)
/SHIELD: J1.S1 (SHIELD), R1.2
/SPI_CIPO-IO1: J2.6, U2.2 (DO(IO1)), U3.35 (SPIQ), U4.2 (DO(IO1))
/SPI_COPI-IO0: J2.8, U2.5 (DI(IO0)), U3.36 (SPID), U4.5 (DI(IO0))
/SPI_SCK: J2.4, RN1.3 (R3.1), U2.6 (CLK), U3.34 (SPICLK), U4.6 (CLK)
/SPI_~CS: RN1.4 (R4.1), U3.33 (SPICS0), U4.1 (~CS)
/SPI_~HLD~-IO3: U2.7 (IO3), U3.31 (SPIHD), U4.7 (IO3)
/SPI_~WP~-IO2: U2.3 (IO2), U3.32 (SPIWP), U4.3 (IO2)
/U0RXD: J2.10, U3.49 (U0RXD)
/U0TXD: J2.9, U3.48 (U0TXD)
/USB_N: R4.1, U3.25 (GPIO19)
/USB_P: R5.1, U3.26 (GPIO20)
/VCC_SPI: C1.1, C2.1, U2.8 (VCC), U3.30 (VDD_SPI), U4.8 (VCC)
/iD+: R5.2, U1.4 (IO2)
/iD-: R4.2, U1.6 (IO1)
/xD+: J1.A6 (D+), J1.B6 (D+), P34.1 (PAD), U1.3 (IO2)
/xD-: J1.A7 (D-), J1.B7 (D-), P33.1 (PAD), U1.1 (IO1)
/~CRESET: J2.3, P31.1, RN1.1 (R1.1), U3.56 (CHIP_PU)
/~LEDG: D2.1 (K), U3.37 (GPIO33)
/~LEDR: D1.1 (K), U3.28 (GPIO21)
/~RGB0: R6.1, U3.8 (GPIO3)
/~RGB1: R9.1, U3.11 (GPIO6)
/~RGB2: R14.1, U3.10 (GPIO5)
GND: AE1.2 (Shield), C1.2, C2.2, C3.1, C4.1, C5.2, C7.2, C8.2, C9.2, C10.2, C11.2, C12.2, C13.2, C14.2, C15.2, C19.2, J1.A1 (GND), J1.A12 (GND), J1.B1 (GND), J1.B12 (GND), J2.5, P24.1, P25.1, P26.1, P35.1 (PAD), R1.1, R2.1, R3.1, R8.2, SW1.2, U1.2 (GND), U2.4 (GND), U3.57 (GND), U4.4 (GND), U5.2 (MODE), U5.6 (GND), U5.7 (GND), Y1.2, Y1.4
unnamed: AE1.1 (A), C11.1, L2.2
unnamed: C3.2, U3.52 (XTAL_N), Y1.3
unnamed: C4.2, U3.53 (KTAL_P), Y1.1
unnamed: C6.2, R7.2, R8.1, U5.3 (FB)
unnamed: C10.1, L2.1, U3.2 (LNA_IN)
unnamed: C8.1, C13.1, FB3.2, U3.1 (VDDA), U3.51 (VDDA), U3.54 (VDDA)
unnamed: C14.1, C15.1, FB2.2, U3.3 (VDD3P3), U3.4 (VDD3P3)
unnamed: C9.1, C19.1, FB1.2, U3.20 (VDD3P3_RTC), U3.27 (VDD3P3_RTC_IO), U3.45 (VDD3P3_CPU)
unnamed: D1.2 (A), R11.1
unnamed: D2.2 (A), R12.1
unnamed: D3.2 (A), R13.1
unnamed: D4.2 (RK), R6.2
unnamed: D4.3 (BK), R14.2
unnamed: D4.4 (GK), R9.2
unnamed: L1.1, U5.1 (SW)
VBUS: C5.1, J1.A4 (VBUS), J1.A9 (VBUS), J1.B4 (VBUS), J1.B9 (VBUS), JP1.1, P32.1 (PAD), U1.5 (VBUS), U5.4 (EN), U5.5 (VIN)
VIN: JP1.2, P29.1

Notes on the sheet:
DCDC
USB
Flash/RAM
Button
LEDs
Extra I/O - Programming
Power Pins
ESP32-S2

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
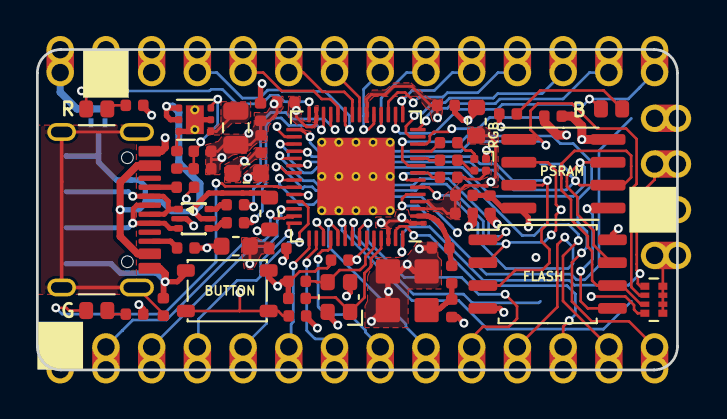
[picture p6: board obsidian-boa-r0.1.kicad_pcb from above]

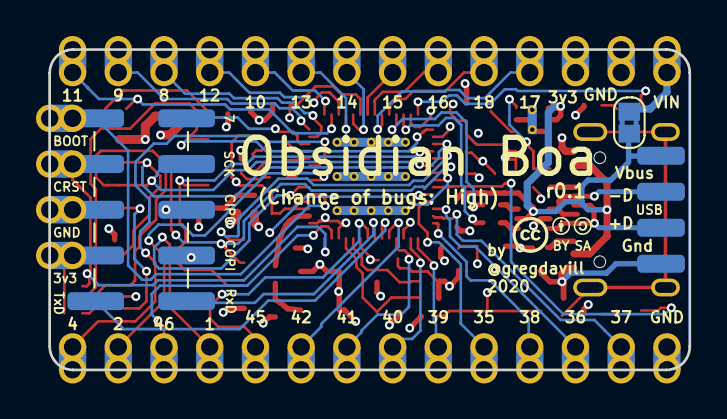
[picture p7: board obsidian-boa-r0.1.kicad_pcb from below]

Board: 4 copper layers, 35.6 x 17.8 mm, 87 parts (6 on the bottom side), 71 nets.

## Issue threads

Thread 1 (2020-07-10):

KiCad 3D rendered not looked like description

manobendro, 2020-07-10:
What is the secret of kiCad 3d rendering? How to render like description image.

gregdavill, 2020-07-11:
The rendering has been created in Autodesk Fusion360 using the `.STEP` output from the KiCad designs. When I have a prototype in hand I'll be replacing it with a photo.

Here is a talk walking through the process: https://www.youtube.com/watch?v=L25B5WaZ2EI

manobendro, 2020-07-11:
Wow! It take lot of effort to look like realistic.

Closed 2020-07-11.

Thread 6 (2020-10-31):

Flash-PSRAM

GlebDen, 2020-10-31:
Hello.
First of all I would like to thank you for the excellent work.
I would like to clarify one point. In your schematic, external memory is W25Q32JVSS (U2 and U4). But in the picture of pcb these are different cases. Perhaps there is an error in the circuit and something like ESP-PSRAM64H was meant ??
I would be grateful for clarifications! Thank you.

gregdavill, 2020-10-31:
Thanks, you're right.

It's a FLASH U4 and PSRAM U2.

Any PSRAM compatible with the ESP32 can be used. I'm using
these because they seem to be the easiest to get: https://lcsc.com/product-detail/RAM_Lyontek-Inc-LY68L6400SLIT_C261881.html

A small oversight I've updated the schematic with correct part numbers

Closed 2020-10-31.

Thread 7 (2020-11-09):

R7 and R8 on pcb layout

GlebDen, 2020-11-09:
Hello again.
I've noticed another odd thing.
On your scheme R7 = 453K and R8 = 100K. But on pcb this numbers are different - 180K both.
According to datasheet of TPS62290 Vout=Vref x (1+R1\R2)
(453\100+1) x 0.6 = 3.318V

gregdavill, 2020-11-09:
Interesting, that probably just needs to be synced up.

453/100 appear to be the correct values

Closed 2020-11-09.

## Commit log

2020-07-06 hw.r0d1: initial commit of KiCad project
    [obsidian-boa-r0.1.kicad_pcb, obsidian-boa-r0.1.kicad_sch, obsidian-boa-r0.1.sch]
2020-07-07 hw.r0d1: Tidy up schematic, plan out layout on PCB
    [obsidian-boa-r0.1.kicad_pcb, obsidian-boa-r0.1.kicad_sch]
2020-07-07 hw.r0d1: Update routing and layout
    [obsidian-boa-r0.1.kicad_pcb, obsidian-boa-r0.1.kicad_sch]
2020-07-07 hw.r0d1: Complete first pass of layout and routing
    [obsidian-boa-r0.1.kicad_pcb, obsidian-boa-r0.1.kicad_sch]
2020-07-07 hw.r0d1: Update 3d models, included 3d render
    [obsidian-boa-r0.1.kicad_pcb]
2020-07-07 hw.r0d1: Cleanup repo
    [obsidian-boa-r0.1.kicad_pcb, obsidian-boa-r0.1.kicad_sch, obsidian-boa-r0.1.sch]
2020-07-07 hw.r0d1: Update 3d files to relative paths
    [obsidian-boa-r0.1.kicad_pcb]
2020-07-08 hw.r0d1: update to route VDD_SPI seperately.
    [obsidian-boa-r0.1.kicad_pcb, obsidian-boa-r0.1.kicad_sch]
2020-07-18 hw.r0d1: Update BOM fields
    [obsidian-boa-r0.1.kicad_sch]
2020-07-18 hw.r0d1: Add Gerbers
2020-08-13 Added a PDF of schematic
2020-08-15 Added JPG with I/O pin names.
2020-08-15 Added label for button to JPG
2020-10-31 hw: Update PSRAM/FLASH part numbers
    - Regenerate schematic
    - Add generated BOM
    #6
    [obsidian-boa-r0.1-bom.csv, obsidian-boa-r0.1.kicad_sch]
2020-11-09 hw: Sync PCB to schematic
    Fixes #7
    [obsidian-boa-r0.1.kicad_pcb]
2021-03-25 hw.r0d1: Create Production outputs
    [obsidian-boa-r0.1-bom.csv, obsidian-boa-r0.1.csv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]

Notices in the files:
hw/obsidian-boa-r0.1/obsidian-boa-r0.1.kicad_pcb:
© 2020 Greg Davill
